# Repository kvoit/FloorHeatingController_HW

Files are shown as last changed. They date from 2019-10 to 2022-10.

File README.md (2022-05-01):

# Floor heating hardware

Contoller board for up to 10 floor heading circuits. Thermostats via MQTT or 868MHz RF (to be developed).
Changed from 1-Wire to 868MHz connectivity in version 2.0.

## Controller

Central controller for my floor heating based on the ESP32.

### Connectivity

- Wifi (MQTT implemented) and BTLE (currently unused) from ESP32.
- AES encrypted and optionaly ATSHA204 authenticated 868MHz radio (to be implemented).
- 10 low-side switched outputs that can be individually controlled and output the input voltage. (Speed limited by the shift registers. Hardware SPI theoretically possible but untested.) Used to power valves.
- 4 Qwiic-compatible I2C ports
- 1 ~7.5V/5V/3.3V/GND ports for powering thermostats.
- JTAG header

### Case

Can be mounted in small breaker boxes on DIN rails. Display fits into the opening for breakers.

### Images

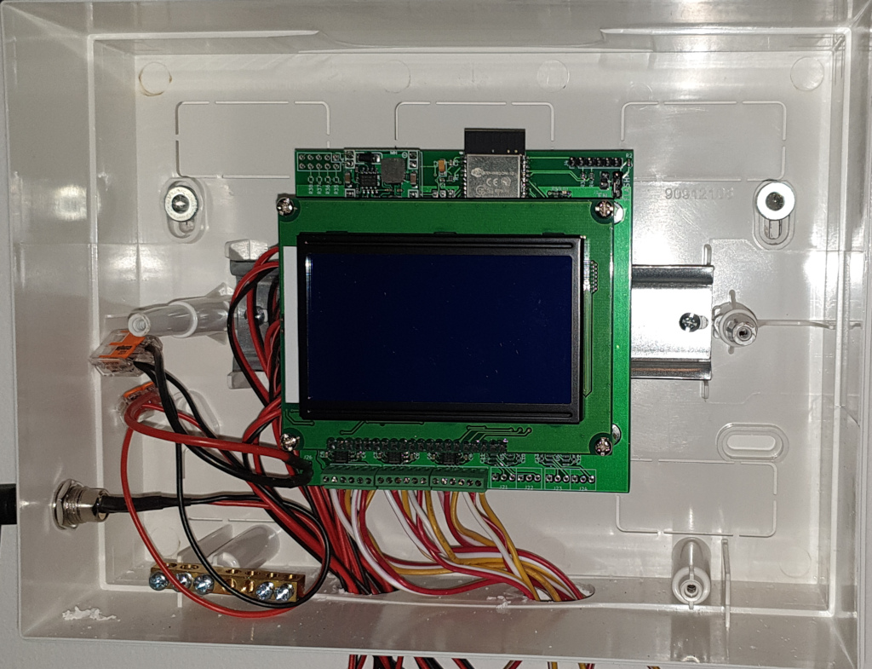
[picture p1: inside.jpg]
Assembled unit (old)


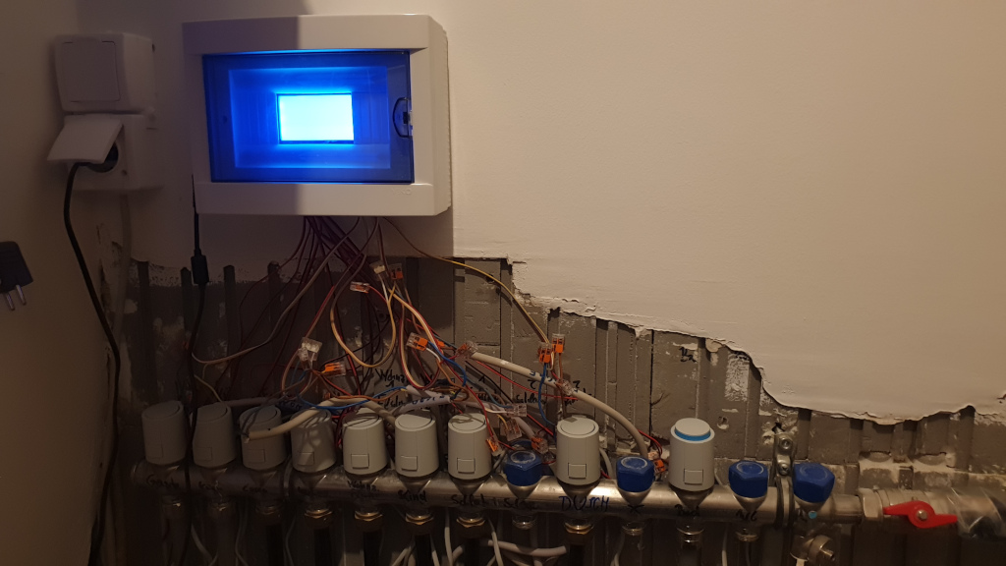
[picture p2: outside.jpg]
Unit in case


### Software

Software [here](https://github.com/kvoit/FloorHeatingController_HW)

## Thermostat

Coming soon ...

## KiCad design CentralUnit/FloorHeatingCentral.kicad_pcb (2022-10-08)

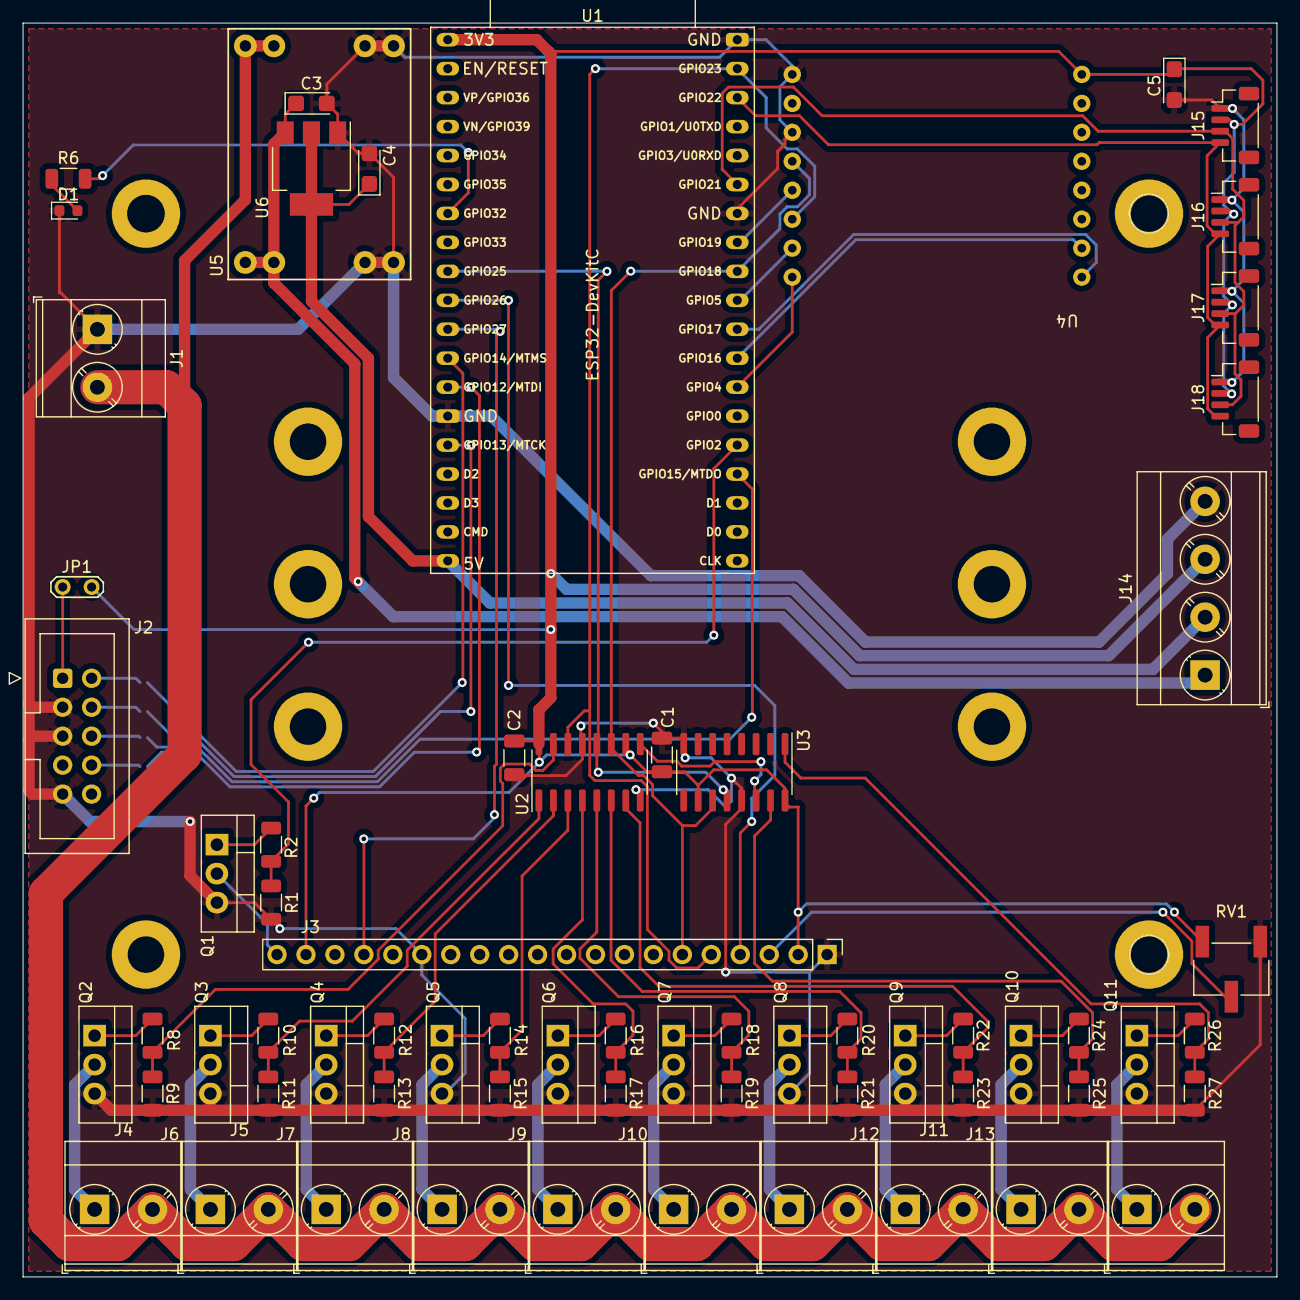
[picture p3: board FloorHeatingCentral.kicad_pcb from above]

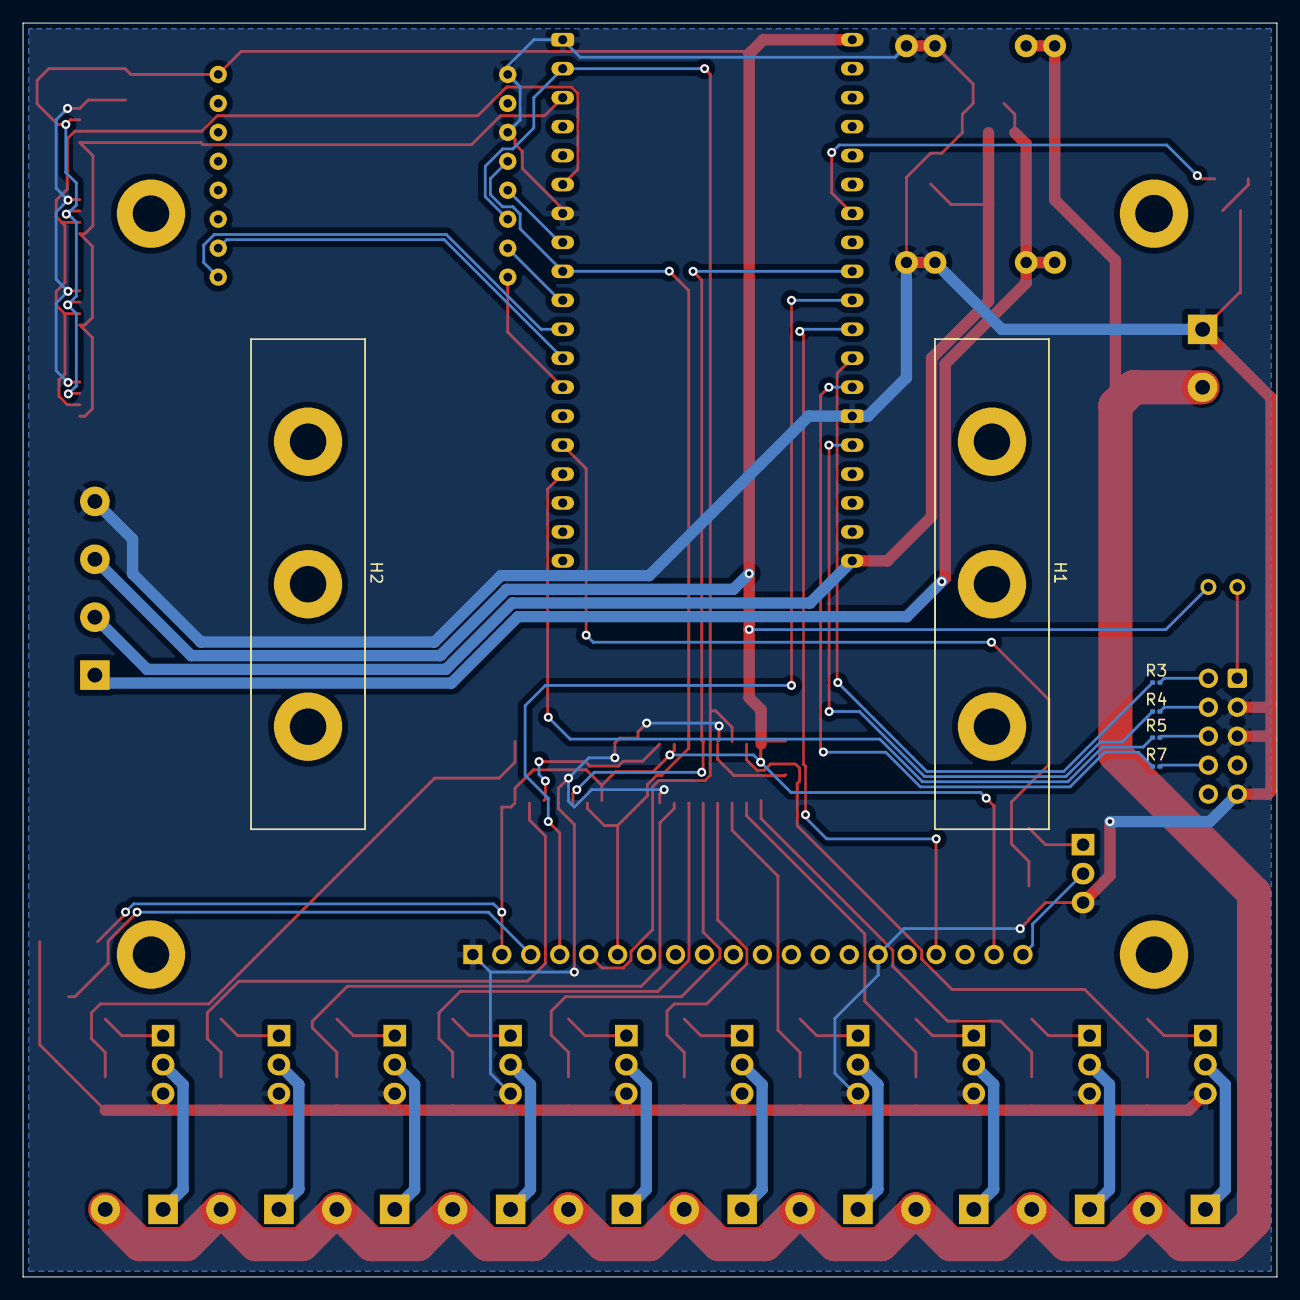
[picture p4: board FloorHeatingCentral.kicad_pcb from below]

Board: 2 copper layers, 110.0 x 110.0 mm, 72 parts (6 on the bottom side), 63 nets.

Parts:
C1, C2: 0.1u; C_1206_3216Metric
C3, C4, C5: 10u; CP_EIA-3216-18_Kemet-A
D1: LED; LED_0603_1608Metric
H1, H2: MountingHole; PCB_DINrail_holder
J1, J4, J5, J6, J7, J8, J9, J10, J11, J12, J13: Screw_Terminal_01x02; TerminalBlock_Phoenix_MKDS-3-2-5.08_1x02_P5.08mm_Horizontal
J2: Conn_02x05_Odd_Even; IDC-Header_2x05_P2.54mm_Vertical
J3: Conn_01x20; 12864_LCD_128x64
J14: Screw_Terminal_01x04; TerminalBlock_Phoenix_MKDS-3-4-5.08_1x04_P5.08mm_Horizontal
J15, J16, J17, J18: Conn_01x04_Male; JST_SH_BM04B-SRSS-TB_1x04-1MP_P1.00mm_Vertical
JP1: Jumper_2_Open; TestPoint_2Pads_Pitch2.54mm_Drill0.8mm
Q1, Q2, Q3, Q4, Q5, Q6, Q7, Q8, Q9, Q10, Q11: Q_NMOS_GDS; TO-220-3_Vertical
R1, R9, R11, R13, R15, R17, R19, R21, R23, R25, R27: 10K; R_1206_3216Metric
R2, R8, R10, R12, R14, R16, R18, R20, R22, R24, R26: 560R; R_1206_3216Metric
R3, R4, R5, R7: 100R; R_0201_0603Metric
R6: 660R; R_1206_3216Metric
RV1: R_POT; Potentiometer_Bourns_3269W_Vertical
U1: ESP32-DevKitC
U2, U3: 74HC595D_118; SOIC-16_3.9x9.9mm_P1.27mm
U4: RFM69-ATSHA-breakout; RFM69HCW_ATSHA204A_Breakout
U5: MP1584
U6: LM1117-5.0; SOT-223-3_TabPin2

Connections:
+3V3: C1.2, C2.2, C5.1, J3.2, J3.19, J14.3, J15.2, J16.2, J17.2, J18.2, JP1.1 (A), RV1.3, U1.1 (3V3), U2.10 (~SRCLR), U2.16 (VCC), U3.10 (~SRCLR), U3.16 (VCC), U4.8 (+3V3)
+5V: C4.1, J14.2, U1.19 (5V), U6.2 (VO)
+7.5V: C3.1, J14.1, U5.3 (VOUT), U6.3 (VI)
+24V: J1.2, J4.2, J5.2, J6.2, J7.2, J8.2, J9.2, J10.2, J11.2, J12.2, J13.2, U5.1 (VIN)
/ATSHA: U1.26 (ADC2_CH0/GPIO4), U4.16 (ATSHA)
/ActuatorConn/GATE: R8.1, R9.1, U2.15 (QA)
/ActuatorConn/ValSW: J4.1, Q2.2 (D)
/DISP_CS: J3.4, U1.10 (DAC_2/ADC2_CH9/GPIO26)
/DISP_RST: J3.17, U1.11 (ADC2_CH7/GPIO27)
/DL_SW: R1.1, R2.1, U1.24 (ADC2_CH2/*GPIO2)
/GND_DL_SW: J3.20, Q1.2 (D)
/LED: R6.2, U1.7 (32K_XP/GPIO32/ADC1_CH4)
/RFM69_CS: U1.29 (*GPIO5), U4.15 (NSS)
/RFM69_IRQ: U1.27 (GPIO16), U4.2 (DIO0)
/RFM69_RST: U1.28 (GPIO17), U4.1 (RST)
/SCL: J15.4, J16.4, J17.4, J18.4, U1.36 (GPIO22)
/SDA: J15.3, J16.3, J17.3, J18.3, U1.33 (GPIO21)
/SR_LATCH: U1.9 (DAC_1/ADC2_CH8/GPIO25), U2.12 (RCLK), U3.12 (RCLK)
/TCK: R4.1, U1.15 (MTCK/GPIO13/ADC2_CH4)
/TDI: R7.1, U1.13 (*MTDI/GPIO12/ADC2_CH5)
/TDO: R5.1, U1.23 (*MTDO/GPIO15/ADC2_CH3)
/TMS: R3.1, U1.12 (MTMS/GPIO14/ADC2_CH6)
/VSPI_MISO: U1.31 (GPIO19), U4.13 (MISO)
/VSPI_MOSI: J3.5, U1.37 (GPIO23), U2.14 (SER), U4.14 (MOSI)
/VSPI_SCK: J3.6, U1.30 (GPIO18), U2.11 (SRCLK), U3.11 (SRCLK), U4.12 (SCK)
/sheet5C0162C8/GATE: R10.1, R11.1, U2.1 (QB)
/sheet5C0162C8/ValSW: J5.1, Q3.2 (D)
/sheet5C0163D9/GATE: R12.1, R13.1, U2.2 (QC)
/sheet5C0163D9/ValSW: J6.1, Q4.2 (D)
/sheet5C0163DC/GATE: R14.1, R15.1, U2.3 (QD)
/sheet5C0163DC/ValSW: J7.1, Q5.2 (D)
/sheet5C0169FB/GATE: R24.1, R25.1, U3.15 (QA)
/sheet5C0169FB/ValSW: J12.1, Q10.2 (D)
/sheet5C0169FE/GATE: R26.1, R27.1, U3.1 (QB)
/sheet5C0169FE/ValSW: J13.1, Q11.2 (D)
/sheet5C01653A/GATE: R18.1, R19.1, U2.5 (QF)
/sheet5C01653A/ValSW: J9.1, Q7.2 (D)
/sheet5C01653D/GATE: R20.1, R21.1, U2.6 (QG)
/sheet5C01653D/ValSW: J10.1, Q8.2 (D)
/sheet5C016537/GATE: R16.1, R17.1, U2.4 (QE)
/sheet5C016537/ValSW: J8.1, Q6.2 (D)
/sheet5C016540/GATE: R22.1, R23.1, U2.7 (QH)
/sheet5C016540/ValSW: J11.1, Q9.2 (D)
GND: C1.1, C2.1, C3.2, C4.2, C5.2, D1.1 (K), J1.1, J2.3, J2.5, J2.9, J3.1, J3.15, J14.4, J15.1, J16.1, J17.1, J18.1, Q1.3 (S), Q2.3 (S), Q3.3 (S), Q4.3 (S), Q5.3 (S), Q6.3 (S), Q7.3 (S), Q8.3 (S), Q9.3 (S), Q10.3 (S), Q11.3 (S), R1.2, R9.2, R11.2, R13.2, R15.2, R17.2, R19.2, R21.2, R23.2, R25.2, R27.2, RV1.1, U1.14 (GND), U1.32 (GND), U1.38 (GND), U2.8 (GND), U2.13 (~OE), U3.8 (GND), U3.13 (~OE), U4.9 (GND), U4.11 (GND), U5.2 (GND_IN), U5.4 (GND_OUT), U6.1 (GND)
unnamed: D1.2 (A), R6.1
unnamed: J2.1, JP1.2 (B)
unnamed: J2.2, R3.2
unnamed: J2.4, R4.2
unnamed: J2.6, R5.2
unnamed: J2.8, R7.2
unnamed: J3.3, RV1.2
unnamed: Q1.1 (G), R2.2
unnamed: Q2.1 (G), R8.2
unnamed: Q3.1 (G), R10.2
unnamed: Q4.1 (G), R12.2
unnamed: Q5.1 (G), R14.2
unnamed: Q6.1 (G), R16.2
unnamed: Q7.1 (G), R18.2
unnamed: Q8.1 (G), R20.2
unnamed: Q9.1 (G), R22.2
unnamed: Q10.1 (G), R24.2
unnamed: Q11.1 (G), R26.2
unnamed: U2.9 (QH'), U3.14 (SER)

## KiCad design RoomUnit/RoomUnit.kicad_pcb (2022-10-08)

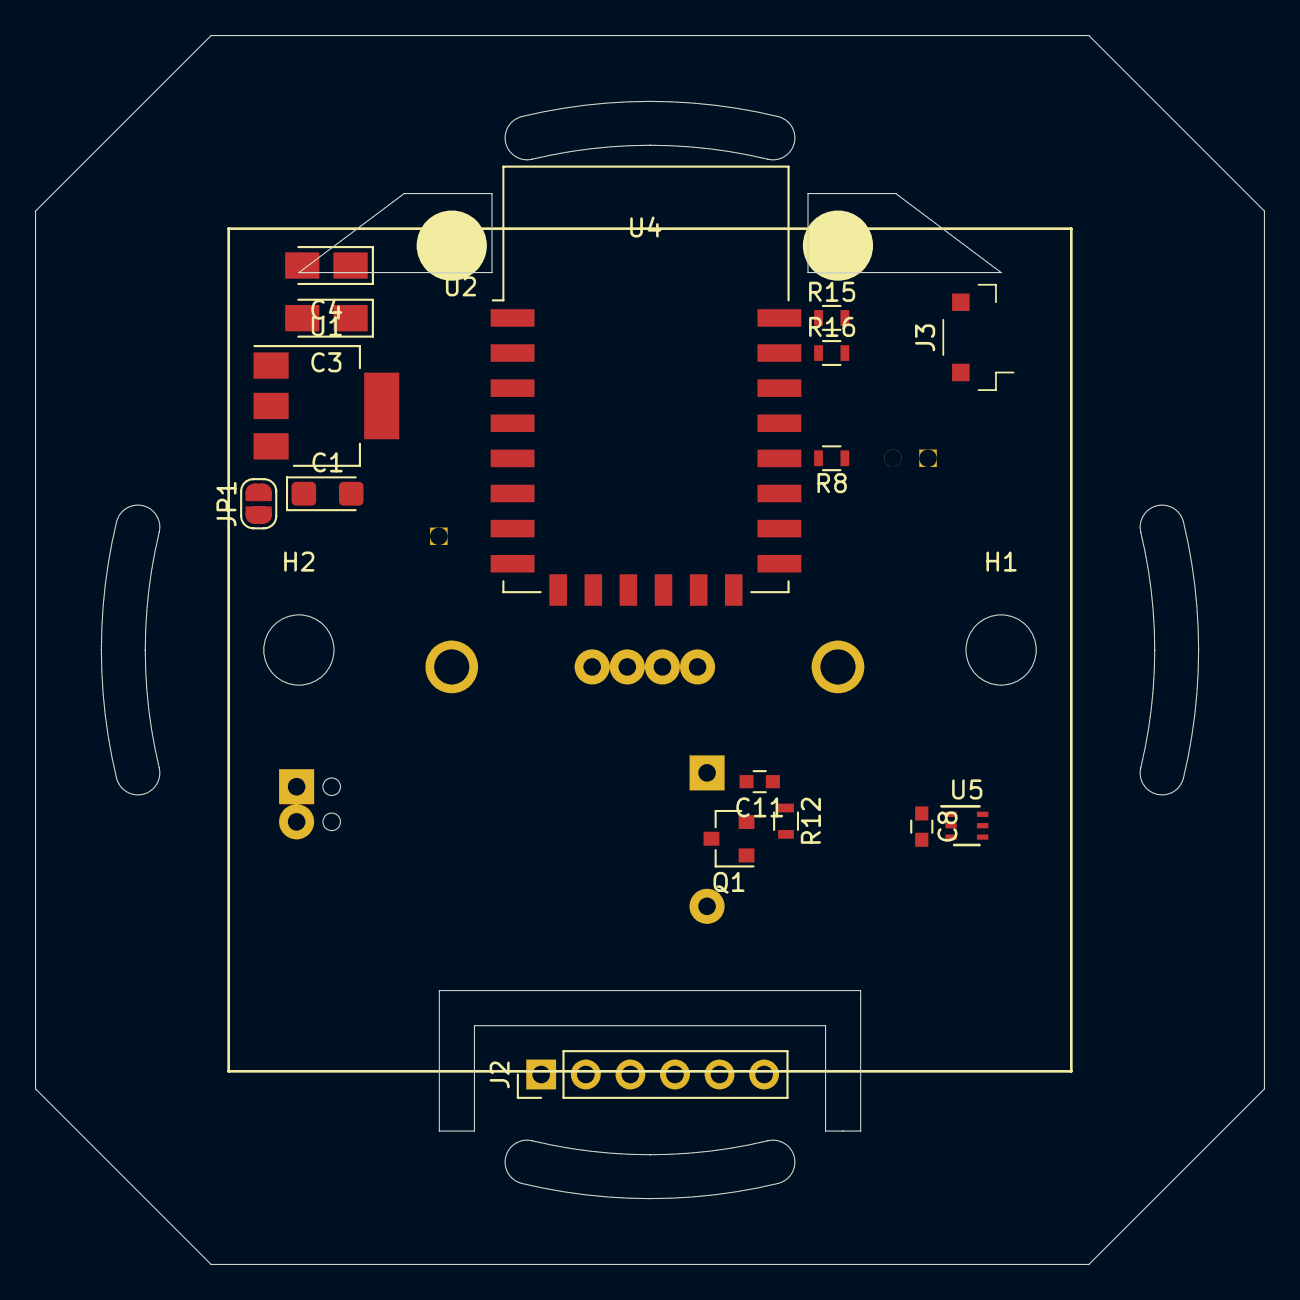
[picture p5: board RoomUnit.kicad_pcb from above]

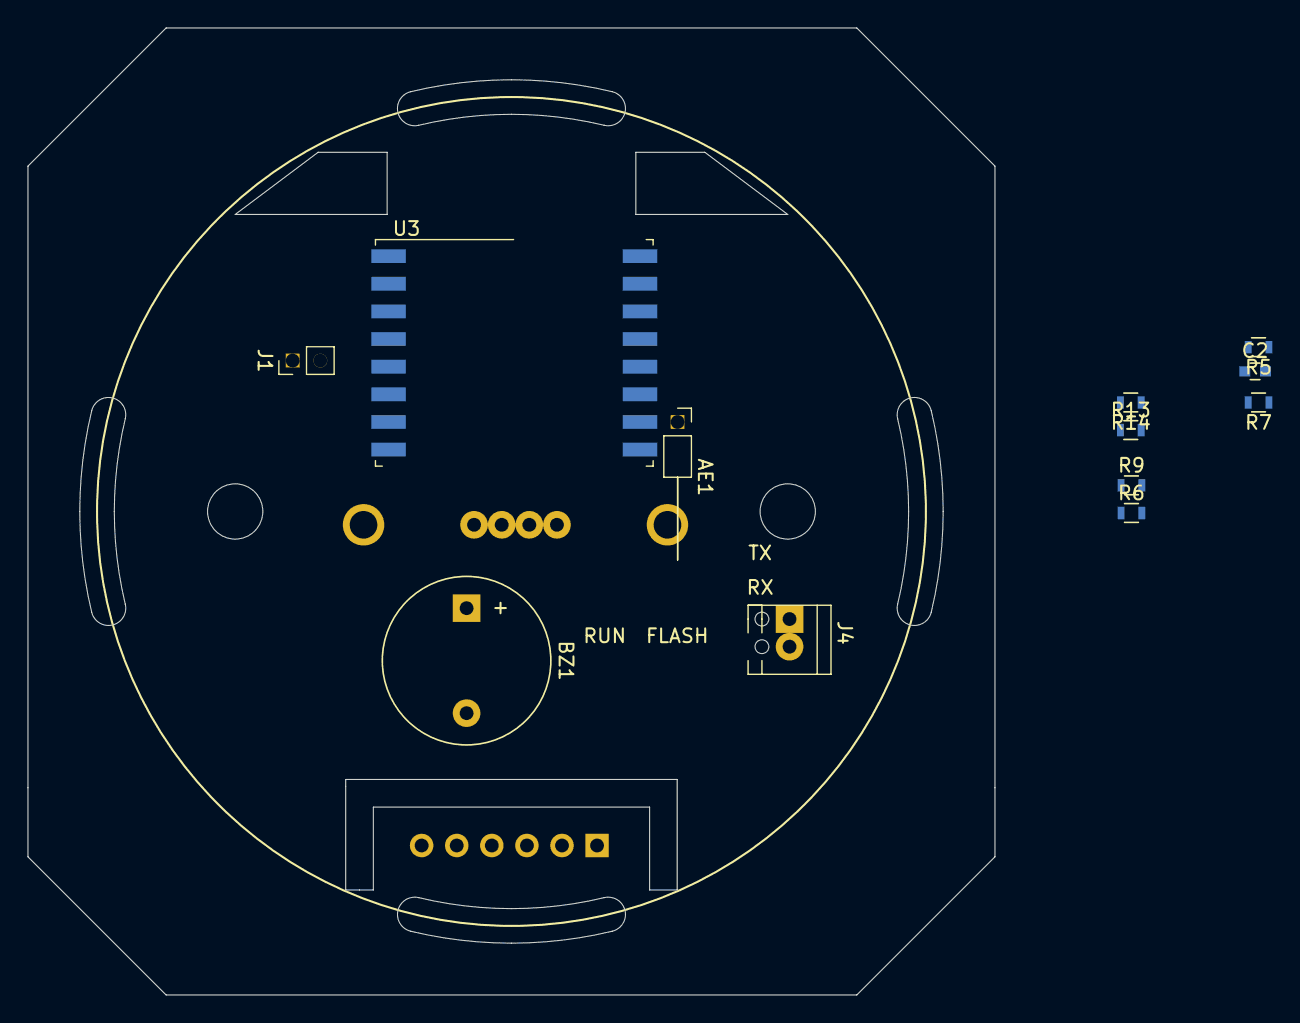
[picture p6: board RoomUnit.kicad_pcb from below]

Board: 2 copper layers, 70.0 x 70.0 mm, 31 parts (12 on the bottom side), 20 nets, no tracks yet.

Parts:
AE1: Antenna; PinHeader_1x01_P2.54mm_Horizontal
BZ1: Buzzer; Buzzer_12x9.5RM7.6
C1: 10u; CP_EIA-3216-18_Kemet-A
C2: 100n; C_0603
C3, C4: 10u; CP_Tantalum_Case-A_EIA-3216-18_Reflow
C8: 100u; C_0603
C11: C; C_0603
H1, H2: MountingHole; MountingHole_4mm
J1: Conn_01x02_Male; PinHeader_1x02_P2.54mm_Vertical
J2: Conn_01x06_Female; PinHeader_1x06_P2.54mm_Vertical
J3: Conn_01x04_Male; JST_SH_BM04B-SRSS-TB_1x04-1MP_P1.00mm_Vertical
J4: Screw_Terminal_01x02; TerminalBlock_Phoenix_MPT-0,5-2-2.54_1x02_P2.54mm_Horizontal
JP1: SolderJumper_2_Bridged; SolderJumper-2_P1.3mm_Open_RoundedPad1.0x1.5mm
Q1: BC817; SOT-23
R5, R6, R7, R8, R9, R13, R14: 10k; R_0603
R12: 2k2; R_0603
R15, R16: 470R; R_0603
U1: LM1117-3.3; SOT-223-3_TabPin2
U2: ESP-12F; ESP-12E
U3: RFM69HW; HOPERF_RFM69HW
U4: 1.3"_128x64OLED_I2C; OLED128x64
U5: LTR-303ALS-01; Lite-On_LTR-303ALS-01

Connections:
+3V3: C3.1, C8.1, J2.1, J2.5, J2.6, J3.4, JP1.2 (B), R5.2, R7.2, R9.2, R13.2, R14.1, U1.2 (VO), U2.8 (VCC), U4.2 (VCC), U5.1 (VDD)
+5V: BZ1.1 (-), C1.1, J4.2, JP1.1 (A), U1.3 (VI)
/BUZZ: R12.2, U2.7 (GPIO13)
/CH_PD: R7.1, U2.3 (EN)
/GPIO0: R8.1, U2.18 (GPIO0)
/GPIO2: R9.1, U2.17 (GPIO2)
/GPIO15: R6.1, U2.16 (GPIO15)
/RST: C2.2, R5.1, U2.1 (~RST)
/RxD: R16.1, U2.21 (GPIO3/RXD)
/SCL: J2.3, R14.2, U2.20 (GPIO5), U4.3 (SCL), U5.4 (SCL)
/SDA: J2.4, R13.1, U2.19 (GPIO4), U4.4 (SDA), U5.6 (SDA)
/TxD: R15.1, U2.22 (GPIO1/TXD)
GND: C1.2, C2.1, C4.2, C8.2, C11.2, J1.1, J2.2, J3.1, J4.1, Q1.2 (E), R6.2, U1.1 (GND), U2.15 (GND), U4.1 (GND), U5.3 (GND)
unnamed: AE1.1 (A), U3.10 (ANA)
unnamed: BZ1.2 (+), Q1.3 (C)
unnamed: C11.1, Q1.1 (B), R12.1
unnamed: J3.2, R15.2
unnamed: J3.3, R16.2
unnamed: J1.2, R8.2
unnamed: U3.9 (GND), U3.11 (GND)

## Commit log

2018-11-27 First version of central controller.
    [ActuatorConn.sch, ESP32-Footprints.kicad_pcb, ESP32-Footprints.sch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]
2018-11-27 Some improvements
    [ActuatorConn.sch, FloorHeatingCentral.kicad_pcb, FloorHeatingCentral.sch]
2018-12-02 Added thermostat unit
    [RoomUnit.kicad_pcb, RoomUnit.sch]
2019-01-12 V2 with fixed SPI bus, status LED und changed flash header
    [FloorHeatingCentral-B.Cu.gbr, FloorHeatingCentral-B.Mask.gbr, FloorHeatingCentral-B.Paste.gbr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]
2019-01-27 Bugfixes: Wrong use of GPIO15, removed header for GPIO2
    [FloorHeatingCentral-B.Cu.gbr, FloorHeatingCentral-B.Mask.gbr, FloorHeatingCentral-B.Paste.gbr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]
2019-09-14 Added alternative resistor to connect LCD brightness to DAC
    [FloorHeatingCentral.kicad_pcb, RoomUnit.kicad_pcb]
2019-10-23 Added possibility to PWM LCD light and updated README
    [FloorHeatingCentral.kicad_pcb, FloorHeatingCentral.sch]
2022-04-27 Major work changing over to 868MHz solution. Current state unfinished
    [ActuatorConn.kicad_sch, FloorHeatingCentral.kicad_pcb, FloorHeatingCentral.kicad_sch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]
2022-04-28 More cleanup and potentially final routing
    [FloorHeatingCentral.kicad_pcb, FloorHeatingCentral.kicad_sch]
2022-04-28 Added power port for thermostats
    [FloorHeatingCentral.kicad_pcb, FloorHeatingCentral.kicad_sch]
2022-04-28 Minor changes
    [FloorHeatingCentral.kicad_pcb]
2022-05-01 Added I2c ports. Final routing. Production.
    [FloorHeatingCentral.kicad_pcb, FloorHeatingCentral.kicad_sch]
2022-05-01 Silkscreen improvement
    [FloorHeatingCentral.kicad_pcb]
